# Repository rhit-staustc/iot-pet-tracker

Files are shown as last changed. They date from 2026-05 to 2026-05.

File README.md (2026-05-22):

# IoT Pet Tracker

A real-time GPS and motion tracking system for pets. Tracker nodes collect GPS location and behavior data (idle/walking/running/sitting) and transmit them over LoRa to a base station, which serves a live webpage over WiFi. Node locations are then displayed visually on a map. Claude was used help us design and implement Websockets and refine the JS for tracking runs as well as storing them locally in the browser.

<p align="center">
  
</p>

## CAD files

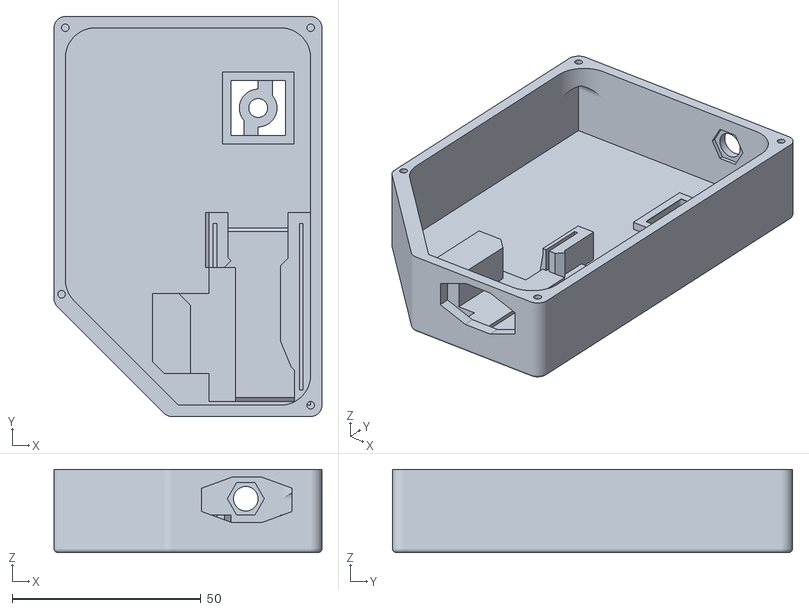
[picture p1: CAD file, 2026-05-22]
V4 Case.stl
71.0 x 106.0 x 22.0

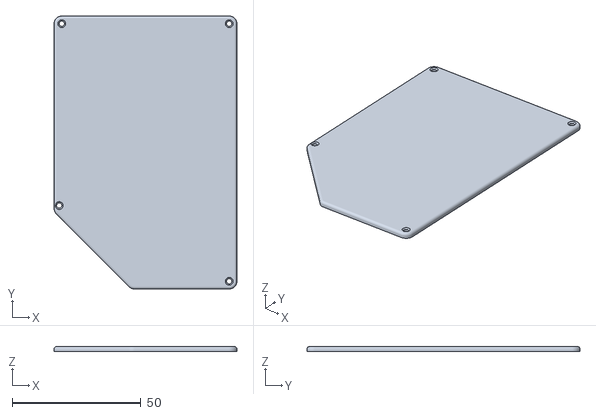
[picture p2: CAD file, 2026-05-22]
V4 Lid.stl
71.0 x 106.0 x 2.00

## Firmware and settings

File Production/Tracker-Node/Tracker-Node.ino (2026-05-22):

#include "Arduino.h"
#include "FastIMU.h"
#include "HT_TinyGPS++.h"
#include "LoRaWan_APP.h"
#include <Wire.h>

#define SDA_PIN 45
#define SCL_PIN 46
#define PIN_GPS_EN 34
#define PIN_GPS_RESET 42
#define GPS_RX_PIN 39
#define GPS_TX_PIN 38
#define AGE_THRESHOLD 5000
#define ADC_Ctrl 37
#define ADC_IN 1
#define MAX_MILLIV 4200
#define MIN_MILLIV 3500

#define RF_FREQUENCY 915000000
#define TX_OUTPUT_POWER 28
#define LORA_BANDWIDTH 0
#define LORA_SPREADING_FACTOR 10
#define LORA_CODINGRATE 1
#define LORA_PREAMBLE_LENGTH 8
#define LORA_FIX_LENGTH_PAYLOAD_ON false
#define LORA_IQ_INVERSION_ON false
#define BOARD_LED 35
#define TX_INTERVAL_MS 500

#define RUN_SPEED_IN_MPH     5
#define WALK_SPEED_IN_MPH    1
#define HEAD_ORIENTATION     accelData.accelZ
#define SITTING_THRESHOLD    0.70
#define ROLL_MIN_RATE        50.0
#define ROLL_ANGLE_THRESHOLD 270.0

uint8_t DEVICE_ID = 0; // 0 = Bryce, 1 = Ely
const float VOLT_DIV = 4.9;

TinyGPSPlus gps;

MPU6500 IMU(Wire1);
calData calib = {0};
AccelData accelData;
GyroData gyroData;

float rollAccum = 0;
unsigned long lastRollTime = 0;
bool rollingDetected = false;
unsigned long ledFlashUntil = 0;

enum BehaviorState : uint8_t {
  BEHAVIOR_IDLE    = 0,
  BEHAVIOR_WALKING = 1,
  BEHAVIOR_RUNNING = 2,
  BEHAVIOR_SITTING = 3,
  BEHAVIOR_ROLLING = 4,
};

struct GPSPacket {
  uint8_t status;  // [behavior(4)|fresh(1)|fix_valid(1)|ID(2)]
  uint8_t battery; // 0-100%
  float lat;
  float lon;
  uint16_t speed;  // mph * 100
  uint16_t course; // degrees * 100
};

typedef enum { LOWPOWER, STATE_TX } States_t;

static RadioEvents_t RadioEvents;
static unsigned long lastPacket = 0;
States_t state;
bool needsBusRecovery = false;

uint8_t getBatteryPercent() {
  digitalWrite(ADC_Ctrl, HIGH);
  uint32_t vBat = analogReadMilliVolts(ADC_IN) * VOLT_DIV;
  digitalWrite(ADC_Ctrl, LOW);
  int percent = ((int)vBat - MIN_MILLIV) * 100 / (MAX_MILLIV - MIN_MILLIV);
  return (uint8_t)constrain(percent, 0, 100);
}

void updateRolling() {
  unsigned long now = millis();
  float dt = (now - lastRollTime) / 1000.0f;
  lastRollTime = now;
  float gyroMag = sqrt(sq(gyroData.gyroX) + sq(gyroData.gyroY) + sq(gyroData.gyroZ));
  if (gyroMag >= ROLL_MIN_RATE) {
    rollAccum += gyroMag * dt;
  } else {
    rollAccum = 0;
  }
  if (rollAccum >= ROLL_ANGLE_THRESHOLD) {
    rollingDetected = true;
    rollAccum = 0;
  }
}

BehaviorState classifyBehavior(double speed_in_mph) {
  if (speed_in_mph >= RUN_SPEED_IN_MPH) {
    return BEHAVIOR_RUNNING;
  } else if (speed_in_mph >= WALK_SPEED_IN_MPH) {
    return BEHAVIOR_WALKING;
  } else {
    if (rollingDetected) {
      rollingDetected = false;
      return BEHAVIOR_ROLLING;
    } else if (HEAD_ORIENTATION <= SITTING_THRESHOLD && HEAD_ORIENTATION > 0) {
      return BEHAVIOR_SITTING;
    } else {
      return BEHAVIOR_IDLE;
    }
  }
}

GPSPacket buildPacket() {
  GPSPacket packet;
  bool fixValid = gps.location.isValid();
  bool fresh = gps.location.age() < AGE_THRESHOLD;
  packet.status = (DEVICE_ID & 0x03);
  if (fixValid) packet.status |= (1 << 2);
  if (fresh)    packet.status |= (1 << 3);
  double speed = gps.speed.mph();
  packet.status |= (classifyBehavior(speed) << 4);
  packet.battery = getBatteryPercent();
  packet.lat = (float)gps.location.lat();
  packet.lon = (float)gps.location.lng();
  packet.speed = (uint16_t)(speed * 100);
  packet.course = (uint16_t)(gps.course.deg() * 100);
  return packet;
}

void OnTxDone(void) {
  ledFlashUntil = millis() + 80;
  digitalWrite(BOARD_LED, HIGH);
  needsBusRecovery = true;
  state = LOWPOWER;
}

void OnTxTimeout(void) {
  Radio.Sleep();
  needsBusRecovery = true;
  state = STATE_TX;
}

void gpsConfig() {
  Serial1.println("$PCAS04,7*1E");
  Serial1.println("$PCAS11,1*1C");
  Serial1.println("$PCAS02,1000*2E");
  Serial1.println("$PCAS03,0,0,0,0,1,0,0,0,0,0,,,0,0*03");
  Serial1.println("$PCAS00*01");
}

void setup() {
  Mcu.begin(HELTEC_BOARD, SLOW_CLK_TPYE);

  Wire1.begin(SDA_PIN, SCL_PIN);
  Wire1.setClock(400000);

  pinMode(PIN_GPS_RESET, OUTPUT);
  digitalWrite(PIN_GPS_RESET, HIGH);

  pinMode(PIN_GPS_EN, OUTPUT);
  digitalWrite(PIN_GPS_EN, LOW);
  delay(1000);
  Serial1.begin(9600, SERIAL_8N1, GPS_RX_PIN, GPS_TX_PIN);
  gpsConfig();

  calib.valid = true;
  calib.accelBias[0] =  0.02;
  calib.accelBias[1] =  0.03;
  calib.accelBias[2] = -0.01;
  calib.gyroBias[0]  =  3.06;
  calib.gyroBias[1]  =  0.45;
  calib.gyroBias[2]  = -0.45;
  IMU.init(calib, 0x68);

  pinMode(ADC_Ctrl, OUTPUT);
  pinMode(BOARD_LED, OUTPUT);
  digitalWrite(BOARD_LED, LOW);

  RadioEvents.TxDone = OnTxDone;
  RadioEvents.TxTimeout = OnTxTimeout;

  Radio.Init(&RadioEvents);
  Radio.SetChannel(RF_FREQUENCY);
  Radio.SetTxConfig(MODEM_LORA, TX_OUTPUT_POWER, 0, LORA_BANDWIDTH,
                    LORA_SPREADING_FACTOR, LORA_CODINGRATE,
                    LORA_PREAMBLE_LENGTH, LORA_FIX_LENGTH_PAYLOAD_ON, true, 0,
                    0, LORA_IQ_INVERSION_ON, 3000);

  state = STATE_TX;
}

void loop() {
  switch (state) {
  case STATE_TX: {
    while (Serial1.available()) gps.encode(Serial1.read());
    if (needsBusRecovery) {
      Wire1.end();
      Wire1.begin(SDA_PIN, SCL_PIN);
      Wire1.setClock(400000);
      needsBusRecovery = false;
    }
    IMU.update();
    IMU.getAccel(&accelData);
    IMU.getGyro(&gyroData);
    updateRolling();
    GPSPacket packet = buildPacket();
    Radio.Send((uint8_t *)&packet, sizeof(GPSPacket));
    lastPacket = millis();
    state = LOWPOWER;
    break;
  }
  case LOWPOWER:
    while (Serial1.available()) gps.encode(Serial1.read());
    IMU.update();
    IMU.getAccel(&accelData);
    IMU.getGyro(&gyroData);
    updateRolling();
    if (ledFlashUntil && millis() > ledFlashUntil) {
      digitalWrite(BOARD_LED, LOW);
      ledFlashUntil = 0;
    }
    Radio.IrqProcess();
    if (millis() - lastPacket >= TX_INTERVAL_MS) {
      Radio.Sleep();
      state = STATE_TX;
    }
    break;
  default:
    break;
  }
}

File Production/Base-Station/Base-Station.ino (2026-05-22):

#include "Arduino.h"
#include "HT_SSD1306Wire.h"
#include "LoRaWan_APP.h"
#include "index_html.h"
#include <ArduinoJson.h>
#include <AsyncTCP.h>
#include <ESPAsyncWebServer.h>
#include <WiFi.h>
#include <Wire.h>

#define RF_FREQUENCY 915000000
#define LORA_BANDWIDTH 0
#define LORA_SPREADING_FACTOR 10
#define LORA_CODINGRATE 1
#define LORA_PREAMBLE_LENGTH 8
#define LORA_SYMBOL_TIMEOUT 0
#define LORA_FIX_LENGTH_PAYLOAD_ON false
#define LORA_IQ_INVERSION_ON false
#define BOARD_LED 35

struct GPSPacket {
  uint8_t status;  // [behavior(4)|fresh(1)|fix_valid(1)|ID(2)]
  uint8_t battery; // 0-100%
  float lat;
  float lon;
  uint16_t speed;  // mph * 100
  uint16_t course; // degrees * 100
};

struct WiFiNetwork {
  const char *ssid;
  const char *password;
};

WiFiNetwork networks[] = {
  {"RHIT-OPEN", ""},
  {"Test", "password"},
  {"ATO Wifi", "ATOest1865"}
};

static SSD1306Wire display(0x3c, 500000, SDA_OLED, SCL_OLED, GEOMETRY_128_64, RST_OLED);
static RadioEvents_t RadioEvents;

AsyncWebServer server(80);
AsyncWebSocket ws("/ws");

unsigned long ledFlashUntil = 0;

bool isRunActive = false;
String currentRunId = "";

void connectWiFi() {
  WiFi.mode(WIFI_STA);
  for (auto &net : networks) {
    WiFi.begin(net.ssid, net.password);
    int attempts = 0;
    while (WiFi.status() != WL_CONNECTED && attempts < 20) {
      delay(500);
      attempts++;
    }
    if (WiFi.status() == WL_CONNECTED) {
      while (WiFi.localIP() == IPAddress(0, 0, 0, 0)) delay(100);
      display.clear();
      display.drawString(0, 0, WiFi.localIP().toString());
      display.drawString(0, 13, "Listening...");
      display.display();
      return;
    }
    WiFi.disconnect();
    delay(200);
  }
}

void broadcastTelemetry(GPSPacket *pkt, int16_t rssi, int8_t snr) {
  StaticJsonDocument<300> doc;
  doc["type"] = "DATA";
  JsonObject p = doc.createNestedObject("payload");
  p["id"]    = pkt->status & 0x03;
  p["fix"]   = (pkt->status >> 2) & 1;
  p["fresh"] = (pkt->status >> 3) & 1;
  p["beh"]   = pkt->status >> 4;
  p["bat"]   = pkt->battery;
  p["lat"]   = pkt->lat;
  p["lng"]   = pkt->lon;
  p["spd"]   = pkt->speed / 100.0;
  p["hd"]    = pkt->course / 100.0;
  p["rssi"]  = rssi;
  p["snr"]   = snr;
  String out;
  serializeJson(doc, out);
  ws.textAll(out);
}

void OnRxDone(uint8_t *payload, uint16_t size, int16_t rssi, int8_t snr) {
  ledFlashUntil = millis() + 80;
  digitalWrite(BOARD_LED, HIGH);

  if (size == sizeof(GPSPacket)) {
    GPSPacket *pkt = (GPSPacket *)payload;
    broadcastTelemetry(pkt, rssi, snr);
  }

  Radio.Rx(0);
}

void onWsEvent(AsyncWebSocket *server, AsyncWebSocketClient *client,
               AwsEventType type, void *arg, uint8_t *data, size_t len) {
  if (type == WS_EVT_CONNECT) {
    StaticJsonDocument<128> doc;
    doc["type"]   = "STATE";
    doc["active"] = isRunActive;
    doc["run_id"] = currentRunId;
    String out;
    serializeJson(doc, out);
    client->text(out);
  }
}

void setup() {
  Mcu.begin(HELTEC_BOARD, SLOW_CLK_TPYE);

  pinMode(BOARD_LED, OUTPUT);
  digitalWrite(BOARD_LED, LOW);

  pinMode(Vext, OUTPUT);
  digitalWrite(Vext, LOW);
  delay(100);
  display.init();
  display.setFont(ArialMT_Plain_10);
  display.clear();
  display.drawString(0, 0, "Searching WiFi...");
  display.display();
  connectWiFi();

  ws.onEvent(onWsEvent);
  server.addHandler(&ws);

  server.on("/", HTTP_GET, [](AsyncWebServerRequest *request) {
    request->send_P(200, "text/html", index_html);
  });

  server.on("/api/run/start", HTTP_POST, [](AsyncWebServerRequest *request) {
    if (!isRunActive) {
      isRunActive = true;
      currentRunId = request->hasParam("id") ? request->getParam("id")->value()
                                             : "run_" + String(millis());
      StaticJsonDocument<64> m;
      m["type"]   = "STATE";
      m["active"] = true;
      m["run_id"] = currentRunId;
      String out;
      serializeJson(m, out);
      ws.textAll(out);
      request->send(200, "application/json", "{\"status\":\"active\"}");
    } else {
      request->send(400, "text/plain", "Run already active");
    }
  });

  server.on("/api/run/stop", HTTP_POST, [](AsyncWebServerRequest *request) {
    if (isRunActive) {
      isRunActive = false;
      StaticJsonDocument<64> m;
      m["type"]   = "STATE";
      m["active"] = false;
      m["run_id"] = "";
      String out;
      serializeJson(m, out);
      ws.textAll(out);
      request->send(200, "application/json", "{\"status\":\"stopped\"}");
    } else {
      request->send(400, "text/plain", "No run active");
    }
  });

  server.begin();

  RadioEvents.RxDone = OnRxDone;
  Radio.Init(&RadioEvents);
  Radio.SetChannel(RF_FREQUENCY);
  Radio.SetRxConfig(MODEM_LORA, LORA_BANDWIDTH, LORA_SPREADING_FACTOR,
                    LORA_CODINGRATE, 0, LORA_PREAMBLE_LENGTH,
                    LORA_SYMBOL_TIMEOUT, LORA_FIX_LENGTH_PAYLOAD_ON, 0, true, 0,
                    0, LORA_IQ_INVERSION_ON, true);
  Radio.Rx(0);
}

void loop() {
  if (WiFi.status() != WL_CONNECTED) connectWiFi();
  ws.cleanupClients(2);

  if (ledFlashUntil && millis() > ledFlashUntil) {
    digitalWrite(BOARD_LED, LOW);
    ledFlashUntil = 0;
  }

  delay(1);

  Radio.IrqProcess();
}

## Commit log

2026-04-24 Added Testing folder with GPS and IMU files
2026-05-05 current working GPS+LoRa code: base station and tracker node
2026-05-05 imu subclassification tested and working for sitting behavior
2026-05-05 fixed rapid response bug
    [Tracker-Node.ino]
2026-05-05 switched to 915MHz
2026-05-08 modified printpacket to output newly added behaviors
2026-05-12 removed serial prints from classifyBehavior method
2026-05-12 Add FastIMU library include and IMU object declarations
    - Include FastIMU.h for IMU sensor support
    - Declare MPU6500 IMU object and calibration data
    - Add AccelData and GyroData structures for sensor readings
2026-05-12 Add behavior classification constants
    Define speed thresholds and IMU-based orientation parameters:
    - RUN_SPEED_IN_MPH: 5 mph threshold for running behavior
    - WALK_SPEED_IN_MPH: 1 mph threshold for walking behavior
    - HEAD_ORIENTATION: calculated from accelerometer X-axis normalized by factor of 8
    - SITTING_THRESHOLD: 0.33 for detecting sitting posture
2026-05-12 Initialize IMU in setup() with calibration
    - Configure I2C Wire communication (pins 6/7, 400kHz clock)
    - Initialize MPU6500 IMU at address 0x68
    - Perform accelerometer and gyroscope calibration with user prompts
    - Print calibration bias values for verification
2026-05-12 Add IMU sensor reading in main loop
    Update IMU sensors in both STATE_TX and LOWPOWER cases:
    - IMU.update(): refresh sensor readings from hardware
    - IMU.getAccel(): read accelerometer data into accelData struct
    - IMU.getGyro(): read gyroscope data into gyroData struct
    Ensures head orientation data is available for behavior classification
2026-05-12 Update project docs: use Bash instead of PowerShell
2026-05-12 Add build scripts and development documentation
    - Add scripts/ directory with build tools for Base Station and Tracker Node
    - build.sh: unified interface for compile, upload, monitor operations
    - Dependency checking for arduino-cli
    - Support for custom COM ports and baud rates
    - Add .gitattributes for consistent line endings (LF for shell scripts)
    - Add comprehensive README with setup, build, and troubleshooting guides
    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
2026-05-12 Add speed filtering to stabilize behavior classification
    Implements an 8-sample moving average filter on GPS speed readings to reduce jitter from GPS noise. This prevents false positives in behavior classification when the device is stationary but GPS reports noisy speeds between 0-2 mph. The filter smooths out single-packet noise spikes while maintaining responsiveness to actual movement.
    [Tracker-Node.ino]
2026-05-13 Remove OLED display and fix IMU from Wire1 to Wire
    - Remove OLED include, declaration, and updateDisplay() function (not needed for production)
    - Switch IMU from Wire1 to Wire to fix FastIMU compatibility (matches working test sketches)
    - Add scripts/monitor-capture.ps1 for native Windows serial monitoring (WSL cannot access COM ports)
    - Update project docs to document IMU on Wire, PowerShell serial capture, and Tracker IMU behavior
    [Tracker-Node.ino]
2026-05-13 i2c scanner
2026-05-13 Update dev workflow to PowerShell-only with direct SerialPort monitor
    - project docs: replace bash wrapper script commands with direct arduino-cli
    PowerShell commands; remove Bash references
    - monitor-capture.ps1: rewrite to use .NET SerialPort directly instead of
    arduino-cli monitor, which doesn't work with ESP32-S3 USB CDC serial
2026-05-13 Fix IMU by switching to Wire1 and recovering bus before each TX
    - Use Wire1 (pins 6/7) for MPU6500 to avoid conflict with OLED hijacking Wire
    - Add Wire1.end()/begin() + IMU.init() at start of each STATE_TX to recover
    from I2C bus lockup caused by 28 dBm LoRa RF corrupting in-flight transactions
    - Add second IMU.init(calib) after calibrateAccelGyro() to restore 2000dps
    range and apply biases (calibrateAccelGyro leaves sensor in 250dps mode)
    - Default monitor-capture.ps1 duration to 20s
    [Tracker-Node.ino]
2026-05-14 Remove dead OnRxDone code and guard bus recovery behind flag
    The tracker is transmit-only; the GPSPacket cast in OnRxDone was never
    used and has been removed. Bus recovery (Wire1.end/begin) now only runs
    when needsBusRecovery is set after TX, avoiding redundant reinit on
    every loop iteration.
    [Tracker-Node.ino]
2026-05-14 Add auto-flash Stop hook with hash-based change detection
    auto-flash.ps1 records MD5 hashes after each successful upload and
    exits early if neither .ino file has changed since last flash, preventing
    spurious flashes on every response. Serial monitor capture runs
    automatically after a successful upload. Settings allow arduino-cli
    compile/upload without permission prompts.
2026-05-14 Address code review feedback
    - Remove debug Serial prints from STATE_TX loop (gyro bias, raw accel/gyro,
    speed, behavior) — printPacket() covers all production-relevant output
    - Remove unused sleepMode global
    - Fix project docs IMU section: document why Wire1 is used and why bus recovery
    is needed after TX (Mcu.begin hijacks Wire to OLED pins; 28 dBm RF corrupts
    in-flight I2C transactions)
    - monitor-capture.ps1: use $PSScriptRoot + monitor-output/ subdir; create dir
    before writing so first run does not fail
    - Ignore monitor-output/*.txt in .gitignore
    [Tracker-Node.ino]
2026-05-14 Address code review feedback
    - Disable DEBUG by default (// #define DEBUG) so production builds produce no debug output
    - Remove broken monitor-capture.sh (arduino-cli monitor incompatible with ESP32-S3 USB CDC)
    - Exclude project config/settings.local.json from version control (machine-specific paths)
    - Add Wire/Mcu.begin warning comment to I2C-Scanner sketch
    [I2C-Scanner.ino, Tracker-Node.ino]
2026-05-14 Update documentation for merged IMU branch
    - README: replace bash/build.sh workflow with PowerShell/arduino-cli commands, remove OLED troubleshooting, add IMU debug and I2C-Scanner notes, update project structure
    - project docs: remove feature/imu-no-oled from active branches, update main branch description to reflect merged IMU/behavior classification
2026-05-21 switched to svg
2026-05-22 fixed imu testing
2026-05-22 added 3D model files
    [V4 Case.stl, V4 Lid.stl]
